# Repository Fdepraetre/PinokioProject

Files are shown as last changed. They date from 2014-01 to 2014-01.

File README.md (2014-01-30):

PinokioProject
==============

pinokio

In the [wiki of this project](https://github.com/Fdepraetre/PinokioProject/wiki) you will find all documentation you need to build the lamp and use it.

[original pinokio site](http://adambendrordesign.wordpress.com/category/mddn-251/)

Python library
--------------
[AX12 python Library](http://pypi.python.org/pypi/dynamixel/1.0.1)

[Python serial library](http://pypi.python.org/pypi/pyserial)

[WXpython](http://wxpython.org/)

[Numpy](http://www.numpy.org/)

[Matplotlib](http://matplotlib.org)

[PyYAML](http://pyyaml.org/)

windows installation
--------------------
if you are under windows you need a 32bit version of python 2.7. You also need to install some extrat library for matplotlib.

* dateutil
* pyparsing
* six
* pytz

[link to download python library for windows](http://www.lfd.uci.edu/~gohlke/pythonlibs/)

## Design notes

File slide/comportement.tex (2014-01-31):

\section{Comportement}
\begin{frame}
  \begin{columns}[c]
    \begin{column}{.5\textwidth}
      \begin{itemize}
        \item Implémentation d'une machine d'état
        \item Trois états :
          \begin{itemize}
            \item Endormi
            \item Recherche de visage
            \item Suivi de visage
          \end{itemize}
      \end{itemize}
    \end{column}
    \begin{column}{.5\textwidth}
      \begin{figure}
        \input{image/stateMachine.tex}
      \end{figure}
    \end{column}
 \end{columns}
\end{frame}

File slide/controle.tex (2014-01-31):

\section{Contrôle des moteurs}
\subsection{Présentation des moteurs}
\begin{frame}
  \frametitle{Présentation des moteurs}
  \begin{columns}[c]
    \begin{column}{.65\textwidth}
           \begin{itemize}
            \item Moteurs utilisés 
            \begin{itemize}
              \item AX-12~ ( 12 kg.cm\up{-1})
              \item MX-28 ( 28 kg.cm\up{-1})
            \end{itemize}
            \item Avantages:
            \begin{itemize}
              \item Bus TTL , une sortie pour tous les moteurs
              \item Communication par bus UART
              \item Gestion de moteur indépendamment ou globalement
            \end{itemize}
          \item Inconvénient:
            \begin{itemize}
              \item Les AX-12 n'ont pas assez de couple
              \item Contrôle PID intégré et réglé sans charge
              \item Moteur pas à pas
            \end{itemize}
          \end{itemize}
        \end{column}
        \begin{column}{.3\textwidth}
          \begin{figure}[ht]
            \centering
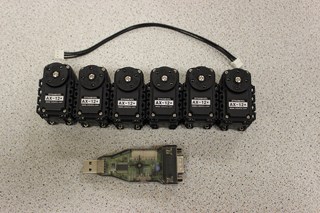
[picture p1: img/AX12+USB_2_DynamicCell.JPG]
            
            \caption{Moteur et interface physique}
          \end{figure}
        \end{column}
      \end{columns}

\end{frame}
\subsection{Configuration et Interface}
\begin{frame}
  \frametitle{Configuration et Interface}
  \begin{columns}[c]
    \begin{column}{.4\textwidth}
      \begin{itemize}
        \item Configuration
          \begin{itemize}
            \item Utilisation de yaml
            \item Port, baudrate, angle limite
          \end{itemize}
        \item Interfaces Utilisateurs
          \begin{itemize}
            \item En ligne de commande
            \item Graphique
          \end{itemize}
      \end{itemize}
    \end{column}
    \begin{column}{.6\textwidth}
      \begin{figure}[ht]
        \centering
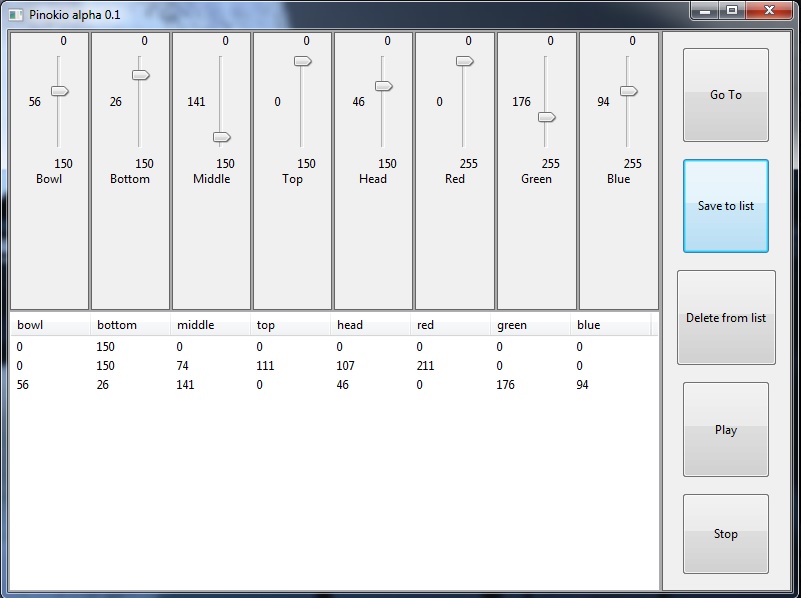
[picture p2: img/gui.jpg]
        
      \end{figure}
    \end{column}
  \end{columns}
\end{frame}
\subsection{Génération de trajectoire}
\begin{frame}
  \frametitle{Génération de trajectoire}
            \begin{figure}
                \begin{center}
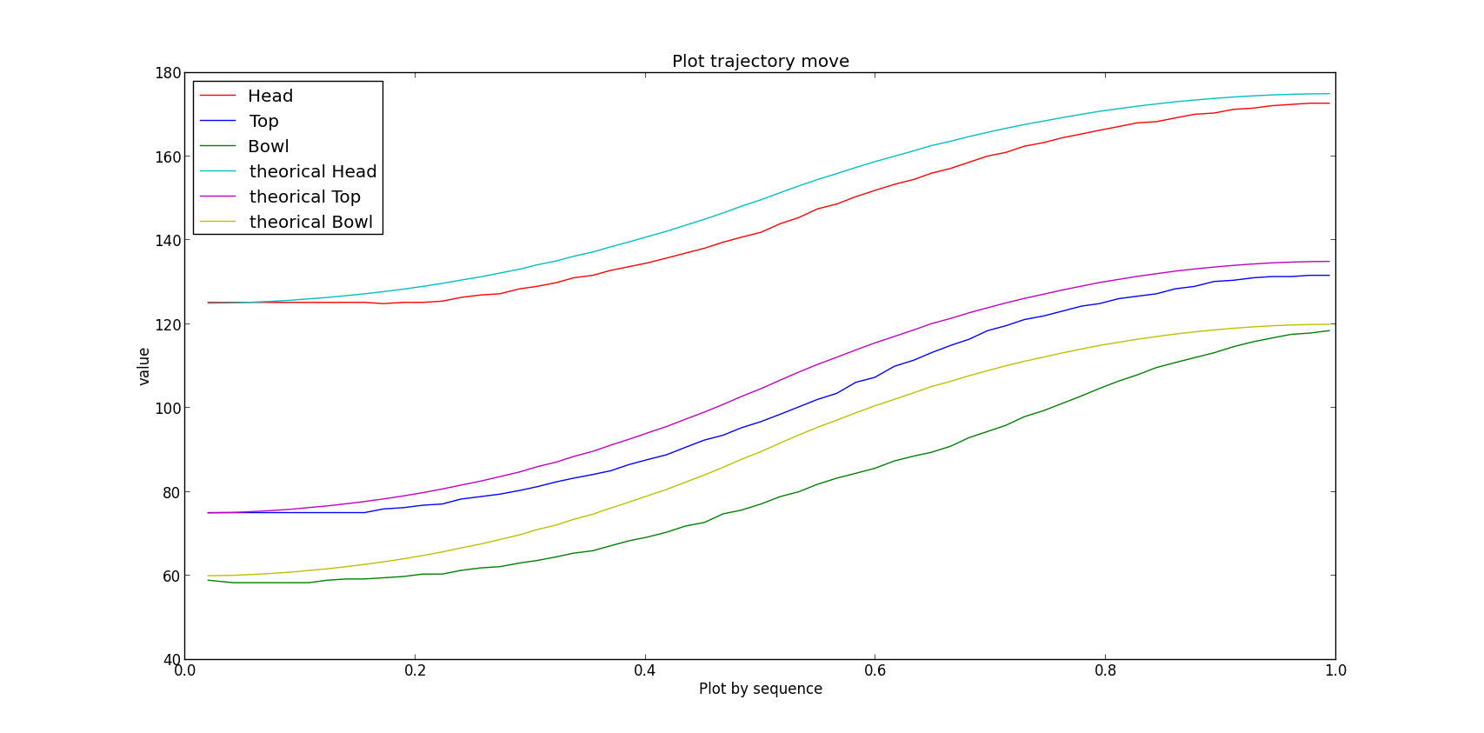
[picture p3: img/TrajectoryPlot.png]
                    
                \end{center}
                \caption{Exemple de génération de trajectoire}
            \end{figure}
\end{frame}

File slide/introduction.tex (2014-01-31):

\section*{Introduction}
\begin{frame}
  \frametitle{Introduction}
  \begin{columns}[c]
    \begin{column}[T]{.5\textwidth}
      \begin{itemize}
        \item Pour l'Inria équipe mnemosyne
        \item Travail demandé
          \begin{itemize}
            \item Reproduire le projet Pinikio
            \item Documenter la réalisation
            \item API simple pour controler le robot
          \end{itemize}
        \item Servira pour l'étude des comportements
      \end{itemize}
    \end{column}
    \begin{column}[T]{.5\textwidth}
      \begin{figure}
        \begin{center}
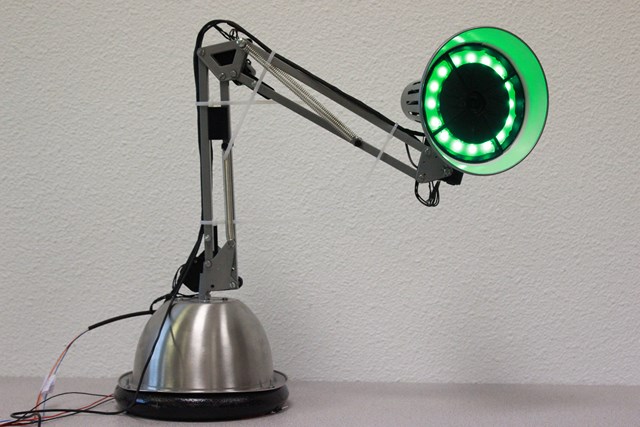
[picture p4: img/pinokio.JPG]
          
        \end{center}
      \end{figure}
    \end{column}
  \end{columns}   
\end{frame}

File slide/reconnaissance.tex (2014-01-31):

\section{Reconnaissance de visage}
\subsection{Détection de visage}
\begin{frame}
  \frametitle{Détection de visage}
  \begin{columns}[c]
    \begin{column}[T]{.5\textwidth}
      \begin{itemize}
        \item Utilisation d'OpenCV
          \begin{itemize}
            \item open source computer vision library
          \end{itemize}
        \item Utilisation de classifieur pour la detection de visage
          \begin{itemize}
            \item Obtention d'un cercle (rayon et centre)
          \end{itemize}
      \end{itemize}
    \end{column}
    \begin{column}[T]{.5\textwidth}
      \begin{figure}
        \begin{center}
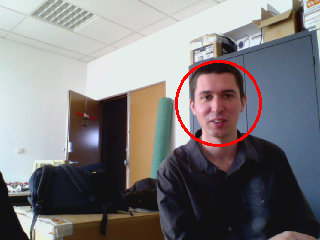
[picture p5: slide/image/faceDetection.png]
          
        \end{center}
      \end{figure}
    \end{column}
  \end{columns}   
\end{frame}

\subsection{Calcul de l'ouverture}
\begin{frame}
  \frametitle{Calcul de l'ouverture}
  \begin{figure}
    \begin{columns}[c]
      \begin{column}[T]{.5\textwidth}
        \input{image/ouverture1.tex}
      \end{column}
      \begin{column}[T]{.5\textwidth}
        \input{image/ouverture2.tex}
      \end{column}
    \end{columns}   
  \end{figure}
\end{frame}

\subsection{Suivi de visages}
\begin{frame}
  \frametitle{Suivi de visages}
  \begin{itemize}
    \item Déterminer :
      \begin{itemize}
        \item la distance au centre de l'image
        \item l'angle horizontal et vertical du visage par rapport au centre 
      \end{itemize}
    \item Déplacer les moteurs de la tête des angles calculés
  \end{itemize}
\end{frame}

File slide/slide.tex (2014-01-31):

\documentclass[handout]{beamer}
 
\usepackage[frenchb]{babel}
\usepackage[T1]{fontenc}
\usepackage[utf8]{inputenc}
\usepackage[footheight=1em]{beamerthemeboxes}
\usepackage{graphics}
\usepackage{graphicx}
\usepackage{tikz}
 
\usetheme{Warsaw}

\title[Projet Pinokio ~~~~~~~~~~~~~~~~~~~~~~~~~~~~~~~~~~~~~~~~~~~~~~ \insertframenumber/\inserttotalframenumber]{Projet Pinokio}
\author[F. Depraetre, T. Lambert, R. Sagean]{Fabien Depraetre, Thibaud Lambert, Romain Sagean}
\institute{ENSEIRB-MATMECA}
\begin{document}

	%% Title Page %%
	\begin{frame}
		\titlepage
	\end{frame}

	%% Plan %%
  \input{introduction.tex}

  \begin{frame}
		\frametitle{Plan}
		\tableofcontents[hideallsubsections]
	\end{frame}

  \input{construction.tex}

  \input{controle.tex}

  \input{reconnaissance.tex}

  \input{comportement.tex}

  \input{conclusion.tex}

\end{document}

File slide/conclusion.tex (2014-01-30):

\section{Conclusion}

\begin{frame}
  \frametitle{Conclusion}
  \begin{itemize}
    \item Beaucoup de temps passé sur la construction
    \item Projet bien documenté
    \item Robot fonctionel et utilisable
    \item Travail à poursuivre
  \end{itemize}
\end{frame}

\begin{frame}
  \begin{center}
    \LARGE Merci de votre attention
  \end{center}
\end{frame}

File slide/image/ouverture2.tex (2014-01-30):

\begin{tikzpicture}[scale=0.5]
 \tikzset{directed/.style={->}} 
  \node[draw, circle, very thick] (CAM) at (0,0) {CAM};
  \node[draw, very thick,color=red] (TARGET) at (6,0) {};
  \node[] (P1) at (3,5.1) {};
  \node[] (P2) at (3,-5.1) {};
  \node[] (P3) at (5.1,3) {};
  \node[] (P4) at (5.1,-3) {};
  \draw[very thick] (CAM) -- (TARGET);
  \draw[very thick] (CAM) -- (P2);
  \draw[dashed] (CAM) -- (P3);
  \draw[dashed] (CAM) -- (P4);
  \draw[directed] (0,0) ++(3,0) node[above right] {$\theta$} arc (0:30:3cm);
  \draw[directed] (0,0) ++(3,0) arc (0:-30:3cm);
%  \fill[very thick] (0.946,0.55) circle (0.2cm);
\end{tikzpicture}

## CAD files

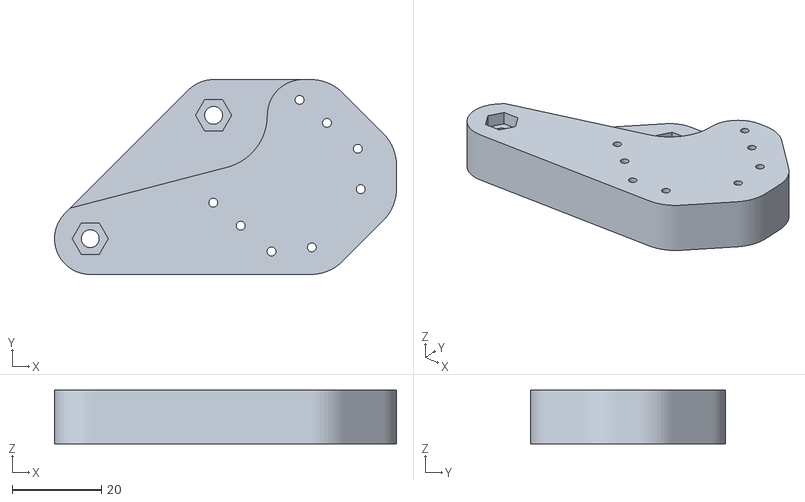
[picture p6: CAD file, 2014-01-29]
parts/bottom_mx28_v1.stl
76.5 x 43.6 x 12.0

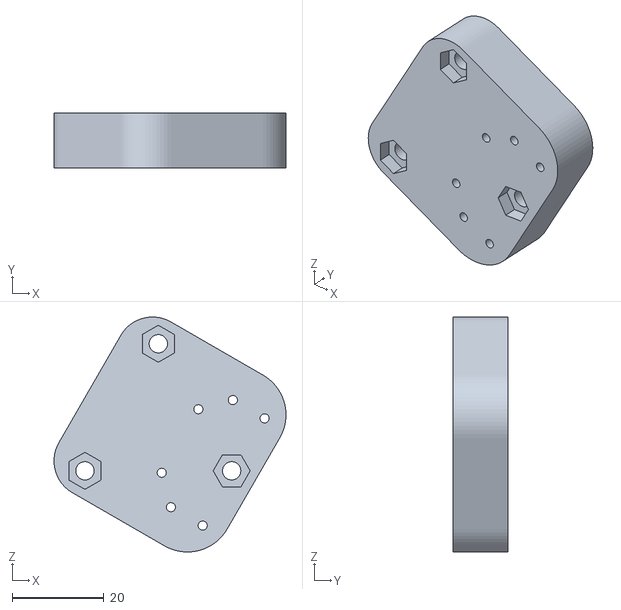
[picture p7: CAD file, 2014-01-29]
parts/oldparts/top_v3.stl
50.6 x 12.0 x 51.3

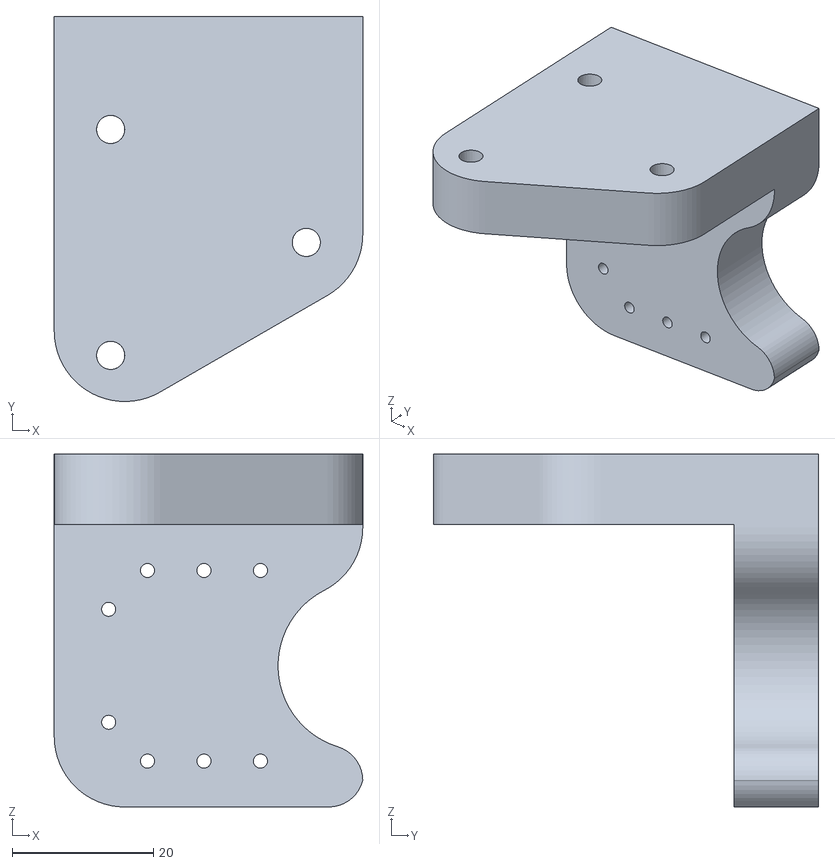
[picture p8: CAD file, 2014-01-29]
parts/top_v4.stl
43.7 x 54.5 x 50.0

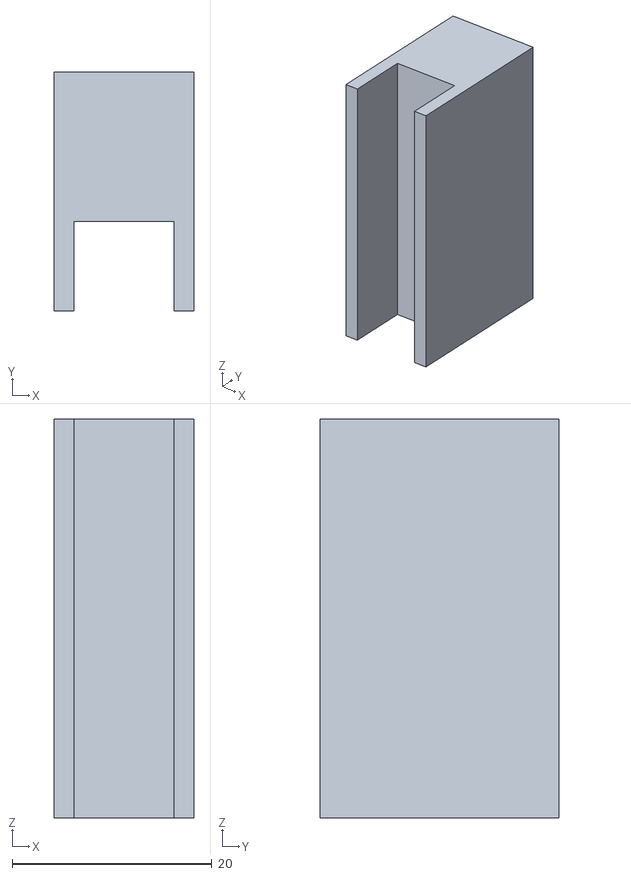
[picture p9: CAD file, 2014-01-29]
parts/bloc.stl
14.0 x 24.0 x 40.0

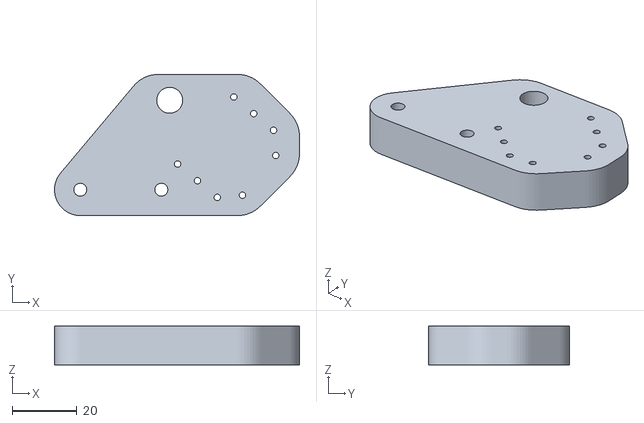
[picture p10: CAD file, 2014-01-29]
parts/oldparts/bottom_ax12_v3.stl
75.6 x 43.6 x 12.0

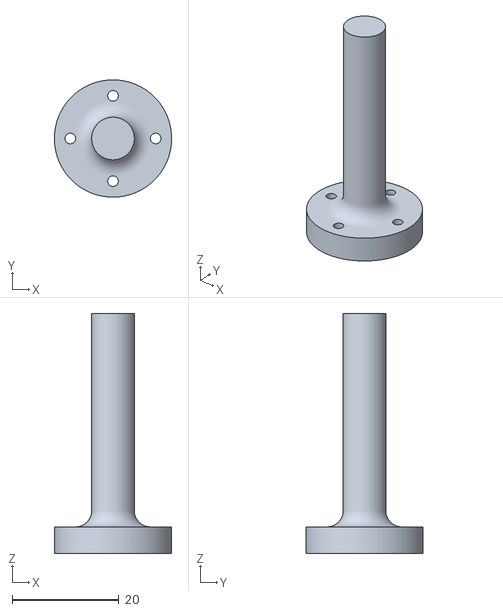
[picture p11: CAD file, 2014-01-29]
parts/ax12tobase.stl
22.0 x 22.0 x 45.0

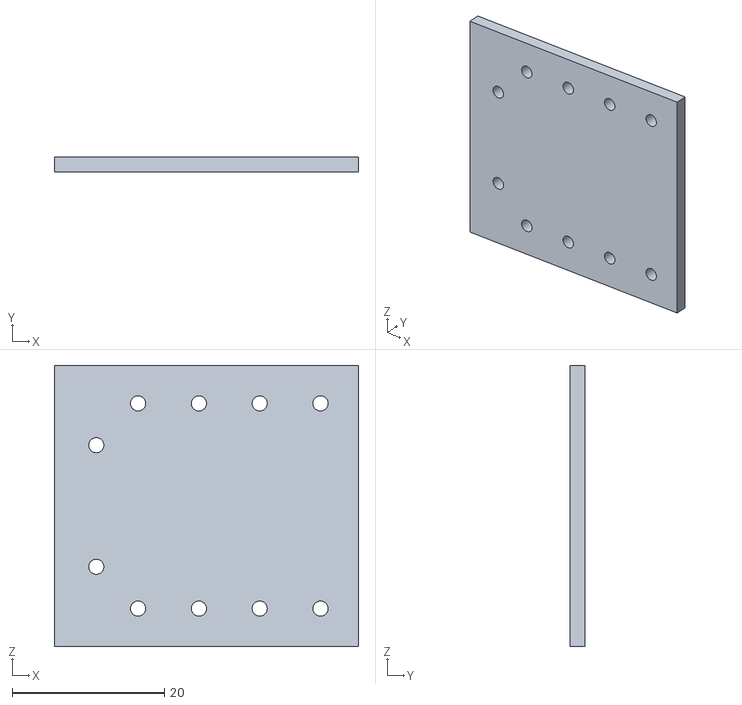
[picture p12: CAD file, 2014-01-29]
parts/oldparts/AX12_gabarit.stl
40.0 x 2.00 x 37.0

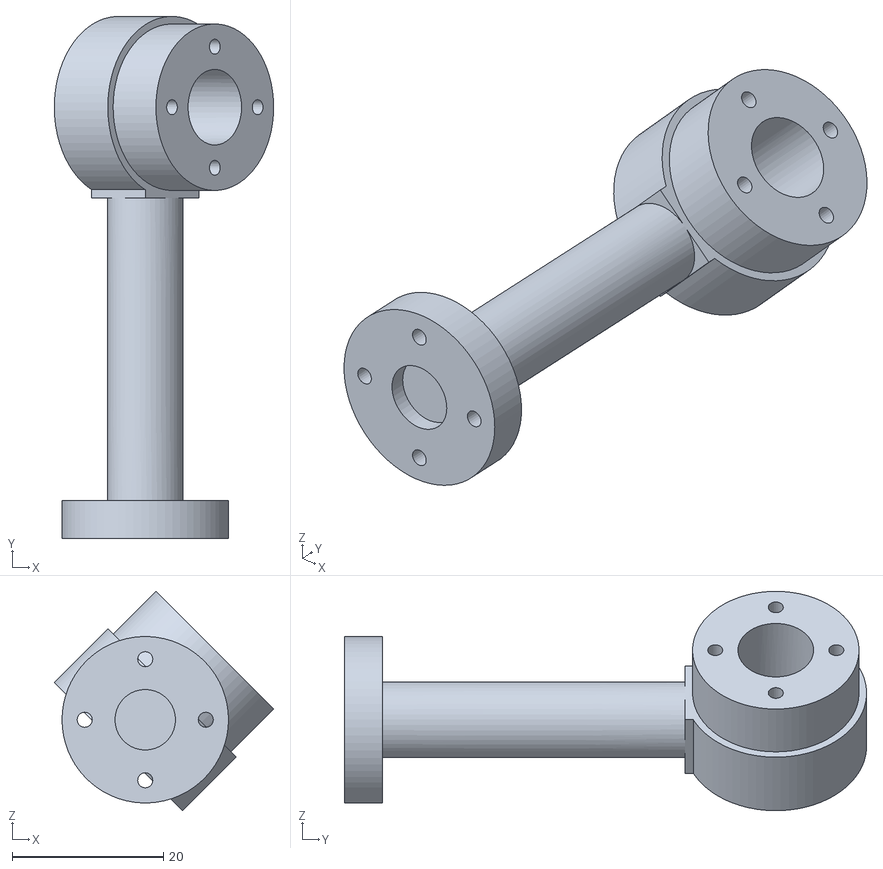
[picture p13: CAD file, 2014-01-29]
parts/neck_v2.1.stl
29.0 x 69.0 x 29.0

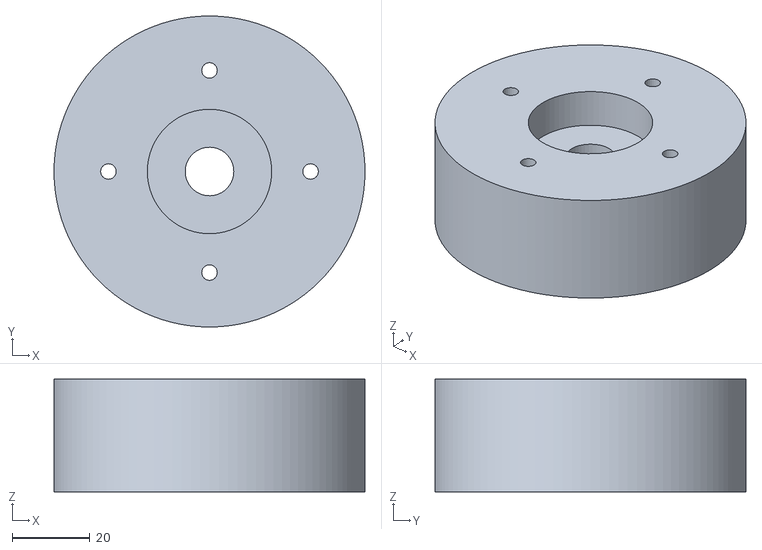
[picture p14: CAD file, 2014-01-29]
parts/bowl_v2.stl
80.0 x 80.0 x 29.0

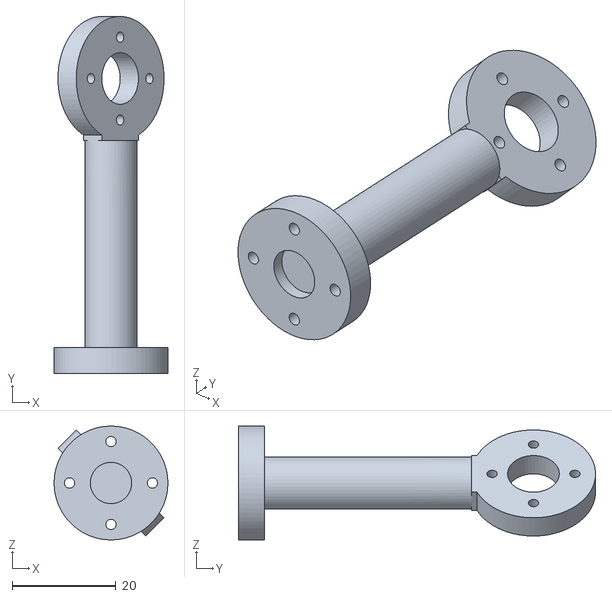
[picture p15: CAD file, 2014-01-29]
parts/oldparts/neck_v2.stl
22.0 x 69.0 x 22.0

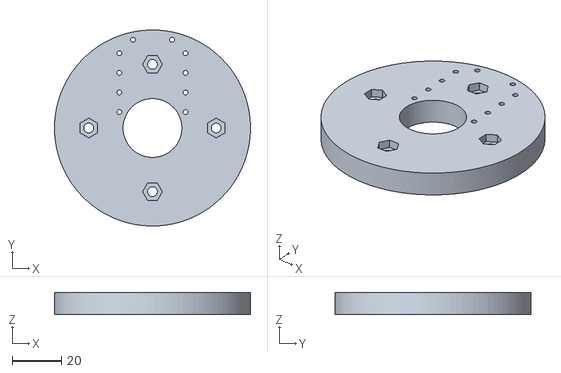
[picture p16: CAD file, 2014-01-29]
parts/bowl_ax12_support_v2.stl
80.0 x 80.0 x 9.00

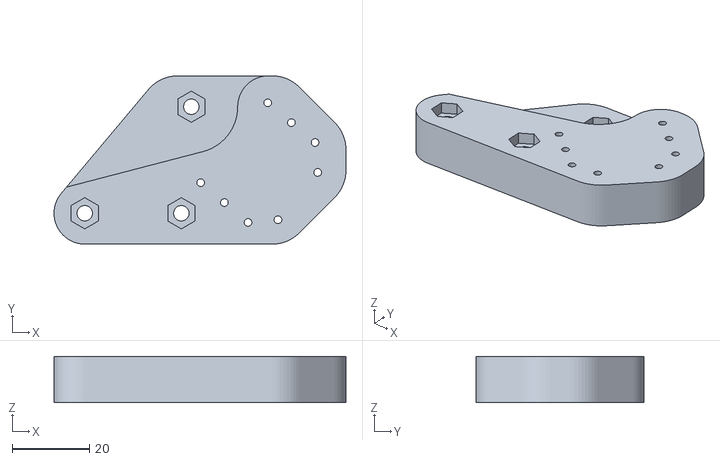
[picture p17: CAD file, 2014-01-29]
parts/oldparts/bottom_right_ax12_v3.stl
75.6 x 43.6 x 12.0

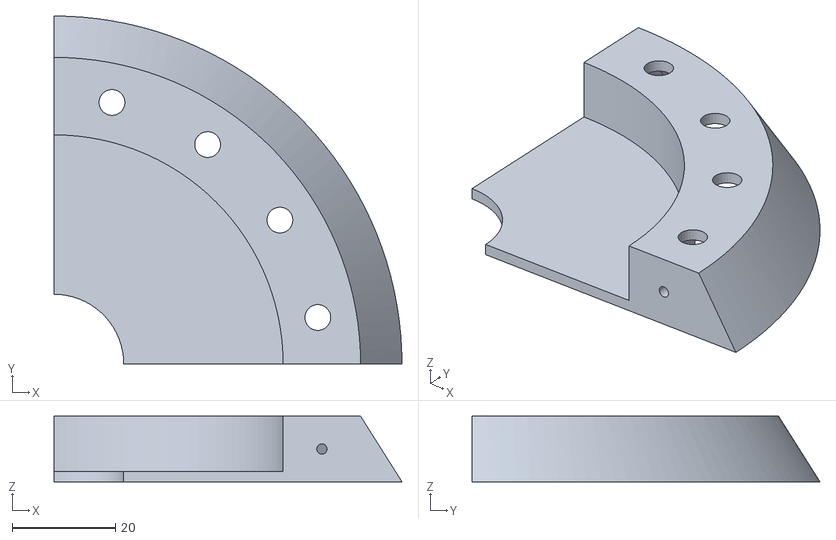
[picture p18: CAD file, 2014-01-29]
parts/Led_circle.stl
67.4 x 67.4 x 12.7

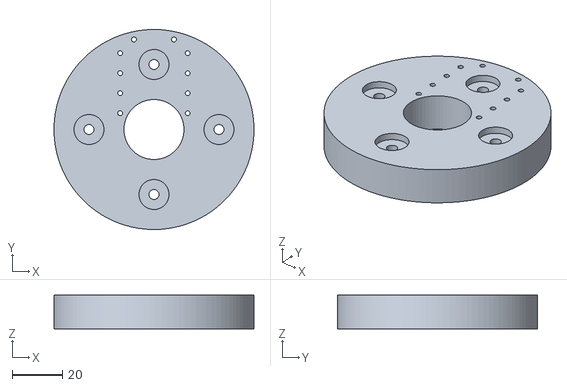
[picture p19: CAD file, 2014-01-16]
parts/oldparts/bowl_ax12_support.stl
80.0 x 80.0 x 13.5

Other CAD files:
parts/head_inside.stl
parts/middle_v1.stl
parts/oldparts/bowl_v1.stl
parts/ax12tobase.ipt
parts/bloc.ipt
parts/bottom_mx28_v1.ipt
parts/bowl_ax12_support_v2.ipt
parts/bowl_v2.ipt
parts/head_inside.ipt
parts/led_circle.ipt
parts/middle_v1.ipt
parts/moving_arm.ipt
parts/moving_arm.stl
parts/neck_v2.1.ipt
parts/oldparts/AX12_gabarit.ipt
parts/oldparts/bottom_ax12_v1.ipt
parts/oldparts/bottom_ax12_v1.stl
parts/oldparts/bottom_ax12_v2.ipt
parts/oldparts/bottom_ax12_v3.ipt
parts/oldparts/bottom_right_ax12_v3.ipt
parts/oldparts/bowl_ax12_support.ipt
parts/oldparts/bowl_v1.ipt
parts/oldparts/neck.ipt
parts/oldparts/neck.stl
parts/oldparts/neck_v2.ipt
parts/oldparts/top_v1.ipt
parts/oldparts/top_v1.stl
parts/oldparts/top_v2.ipt
parts/oldparts/top_v2.stl
parts/oldparts/top_v3.ipt
parts/top_circle.ipt
parts/top_circle.stl
parts/top_v4.ipt

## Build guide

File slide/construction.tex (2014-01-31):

\section{Construction}

\subsection{Fixation des moteurs}
\begin{frame}
  \frametitle{Fixation des moteurs}
  \begin{columns}[c]
    \begin{column}[c]{.5\textwidth}
      \begin{itemize}
        \item moteur vissé sur la pièce en plastique
        \item pièces en plastique vissées sur les articulations
        \item empreinte pour les écrous
        \item facile à assembler et désassembler
      \end{itemize}
    \end{column}
    \begin{column}[c]{.5\textwidth}  
      \begin{figure}
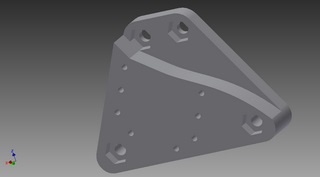
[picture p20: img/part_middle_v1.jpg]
        			
      \end{figure}
    \end{column}
  \end{columns}
\end{frame}

\subsection{Problèmes rencontrés}
\begin{frame}
  \frametitle{Problèmes rencontrés}
  \begin{columns}[c]
    \begin{column}[c]{0.5\textwidth}
	  \begin{itemize}
	    \item pièce bottom 
	      \begin{itemize}
	        \item 1*AX12
	        \item 2*AX12 
	        \item 1*MX28
	        \item raccourcissement des tubes
	      \end{itemize}
	    \item pièce top
	      \begin{itemize}
	        \item buté contre le plastique
	        \item inversement des axes de rotation des moteurs
	      \end{itemize}
	    \item pièce neck
	      \begin{itemize}
	        \item casse de la pièce
	      \end{itemize}
	  \end{itemize}
    \end{column}
    \begin{column}[c]{0.5\textwidth}
      \begin{figure}
      	\begin{center}
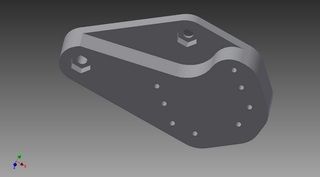
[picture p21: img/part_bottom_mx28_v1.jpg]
      		
      	\end{center}      
      \end{figure}
    \end{column}
  \end{columns}
\end{frame}

\subsection{Contrôle des LED}
\begin{frame}
  \frametitle{Contrôle des LED}
  \begin{columns}[c]
    \begin{column}[T]{0.5\textwidth}
      \begin{itemize}
        \item arduino
        \item utilisation de transistors
        \item communication série pour changer de couleur
      \end{itemize}
    \end{column}
    \begin{column}[T]{0.5\textwidth}
      \begin{figure}
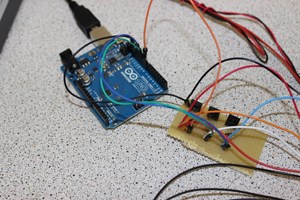
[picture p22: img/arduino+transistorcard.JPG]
        
      \end{figure}
    \end{column}
  \end{columns}
\end{frame}

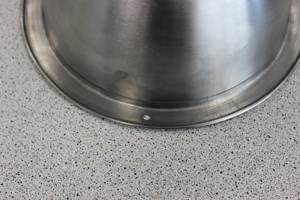
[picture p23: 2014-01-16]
img/bowl_step2.JPG

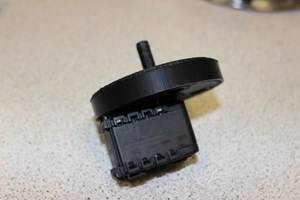
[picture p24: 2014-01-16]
img/base_step6.JPG

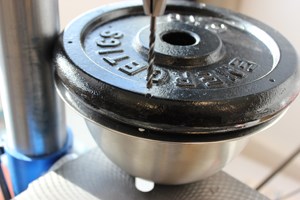
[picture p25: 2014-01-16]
img/bowl_step1.JPG

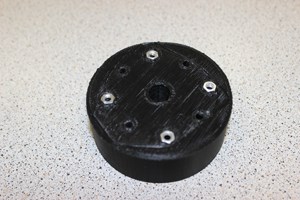
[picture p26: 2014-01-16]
img/base_step1.JPG

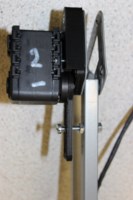
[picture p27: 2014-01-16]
img/joint2_step7.JPG

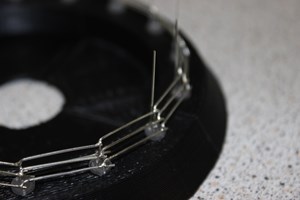
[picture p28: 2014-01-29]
img/led_step_5.JPG

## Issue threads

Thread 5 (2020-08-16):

arduino

marianne1901, 2020-08-16:
I know it has been a long time since you've been here but your project is so awesome that I hope you can answer my question...
I downloaded everything, build the entire lamp but I do not know where to start with the software...
Where can I find the initial / starting sketch for Arduino?

Hope to hear from you!

scauglog, 2020-08-16:
Indeed this was a long time ago. The arduino is only used to control the led. You should upload the .ino file in src/arduino/RGB_led_serial_control to your arduino. To control the actuator (dynamixel) you need a USB to dynamixel adaptator. to control the lamp you have
- a python GUI in `python src/prog/guiClient.py`
- the demo (sleep, search face and follow) `python src/prog/behaviorClient.py`
You need to have a python 2.7 client on your machine with library listed in the Readme.

marianne1901, 2020-08-17:
I am really thankful!
I ordered dynamixel actuators but it's taking too long so I already build it with cheap MG995 servo's.
Hoping they could do the job also if I altered the .ino file.
I think I have to be patient and wait a little longer for the dynamixel actuators.
Thanks again, and when the arrive I will give you s short notice how everything went!

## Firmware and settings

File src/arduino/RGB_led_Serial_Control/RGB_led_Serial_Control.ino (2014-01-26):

int red=9;
int green=10;
int blue=11;

int length=4; //buffer length
byte byteCount;
char endCmd='\n';

long time=0;
int periode = 10000;
int value;
boolean fading=false;
char color;

void setup(){
  pinMode(red,OUTPUT);
  pinMode(green,OUTPUT);
  pinMode(blue,OUTPUT);
  Serial.begin(9600);
  Serial.setTimeout(10);
   analogWrite(red,0);
   analogWrite(green,0);
   analogWrite(blue,0);
}

void loop(){
 char buffer[length];
 byteCount=-1;
 byteCount=Serial.readBytesUntil(endCmd, buffer, length); //read length char or until endCmd
 if(byteCount==4 && buffer[0]=='l'){
   analogWrite(red,buffer[1]);
   analogWrite(green,buffer[2]);
   analogWrite(blue,buffer[3]);
   fading=false;
 }
 if(byteCount==3 && buffer[0]=='f')
 {
   fading=true;
   color=buffer[1];
   periode=buffer[2]*100;
   analogWrite(red,0);
   analogWrite(green,0);
   analogWrite(blue,0);
 }
 if(fading){
   time = millis();
   value = 128+127*cos(2*PI/periode*time);   
   if(color=='r'){
     analogWrite(red,value);
   }else if (color=='g'){
     analogWrite(green,value);
   }else if (color=='b'){
     analogWrite(blue,value);
   }
 }
 
}

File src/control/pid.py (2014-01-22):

import time


class PIDcontroler:

  def __init__(self,proportionalCoeff,integralCoeff,derivateCoeff,maxIntegral=0,maxDerivate=0,length=1):

    self.proportionalCoeff = proportionalCoeff
    self.integralCoeff     = integralCoeff
    self.derivateCoeff     = derivateCoeff
    self.maxIntegral       = maxIntegral
    self.maxDerivate       = maxDerivate
    self.lastIn            = []
    self.integralValue     = []
    self.timeInit = time.time()

    for i in range(length):
      self.lastIn            += [0]
      self.integralValue     += [0]

  def update(self,reference,returnValue):

    derivate = []
    error    = []
    command  = []
    
    timeElapsed = time.time() - self.timeInit

    for i in range(len(reference)):
      derivate += [0]
      error    += [0]
      command  += [0]

      error[i] += reference[i] - returnValue[i]
      self.integralValue[i] += error[i] * timeElapsed
      if self.maxIntegral !=0:
        max(self.integralValue[i],self.maxIntegral)

      derivate[i] = error[i] - self.lastIn[i] / timeElapsed
      if self.maxDerivate != 0:
        max(derivate[i],self.maxDerivate)

      command[i] = error[i] * self.proportionalCoeff + self.integralValue[i] * self.integralCoeff + derivate[i] * self.derivateCoeff

      print "error " + str(error)
      print "intValue " +str(self.integralValue)

    self.lastIn = error

    return command


  time.sleep(2)
if (__name__)=='__main__':


  pid = PIDcontroler(2,0,0,maxIntegral= 500,length=1)
  positionMesured = [[10],[40],[70],[140],[149],[149],[149],[149],[149]]

  outPid = []
#  time.sleep(0.5)
  outPid = pid.update([150],[2])
  print outPid



  for i in range(len(positionMesured)):
      
      outPid = pid.update([150],positionMesured[i])
      time.sleep(0.5)
      print "outPid" + str(outPid) + "\n"

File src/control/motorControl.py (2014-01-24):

import sys
import dynamixel
import time
import random
import sys
import optparse
import plot
sys.path.insert(0, "../settings/")
import settings
import math

class Motor:

  def __init__(self,motor,name,minAngle = 0,maxAngle = 300 ):
    self.motor    = motor
    self.maxAngle = maxAngle
    self.minAngle = minAngle
    self.valeur   = 0
    self.name     = name

  def setAngle(self,angle):
    """ Set the motor angle """
    if angle > self.maxAngle or angle < self.minAngle:
      print "Angle out of range"
      print "motor : " + str(self.name)
      print "value : " + str(angle)
      print "range : [" + str(self.maxAngle) + "," + str(self.minAngle) + "]"
    else:
      if self.name == "bottom":
        fact = 6.82
      else:
        fact = 3.41
      self.motor.goal_position = int(fact * angle)

  def setSpeed(self,speed):
       self.motor.moving_speed = speed

  def setSynchronize(self,synchronized):
       self.motor.synchronized = synchronized

  def readMotorPosition(self):
      if self.name == "bottom":
        fact = 6.82
      else:
        fact = 3.41
      self.motor.read_all()
      return self.motor.current_position / fact
  
  def getRange(self):
    return [self.minAngle,self.maxAngle]


class MotorControl:
   
  def __init__(self,settings):
    self.portName       = settings['port']
    self.baudRate       = settings['baudRate']
    self.motorConfig    = settings['motorConfig']
    self.motors         = [] 
     
    # Establish a serial connection to the dynamixel network.
    # This usually requires a USB2Dynamixel
    serial   = dynamixel.SerialStream(port        = self.portName, baudrate = self.baudRate, timeout = 1)
    self.net = dynamixel.DynamixelNetwork(serial)
    self.idList = []
    self.nameList = []

    print "Scanning for Dynamixels..."
    for conf in self.motorConfig:
      self.idList += [conf[0]]
      self.nameList += [conf[3]]
    self.net.scan(min(self.idList),max(self.idList))
    for conf in self.motorConfig:
      if conf[0] in [motor.id for motor in self.net.get_dynamixels()]:
        print "motor " + str(conf[3]) + " has been found"
        self.motors += [Motor(self.net[conf[0]],conf[3],conf[1],conf[2])]
      else:
        print "motor " + str(conf[3]) + " has not been found"
        self.motors += [None]
    self.setAllSpeed()
        
     
  def setAllSpeed(self,speed=100):
    """ Set the speed for every motors """
    # Ping the range of servos that are attached
    for motor in self.motors:
      if motor != None :
        motor.setSpeed(speed)

  def setSynchronize(self,synchronized = True):
    """ Set the synchronization for every motors """
    for motor in self.motors:
      if motor != None :
        motor.setSynchronize(synchronized)

  def setMotorsById(self,values):
    """ Set the angle motor by ID ( values is a list of tuple [ motorId , Angle]) """
    for val in values:
      if val[0] in self.idList :
        index = self.idList.index(val[0])
        if self.motors[index] != None:
          self.motors[index].setAngle(val[1]) 
    self.net.synchronize()
    #time.sleep(0.1)

  def setMotorsByName(self,values):
    """ Set the angle motor by name ( values is a list of tuple [ motorName , Angle]) """
    for val in values:
        if val[0] in self.nameList :
            index = self.nameList.index(val[0])
            if self.motors[index] != None:
                self.motors[index].setAngle(val[1]) 
    self.net.synchronize()
    #time.sleep(0.1)

  def readAllMotors(self):
    """Return each motor position in tick motor  """
    out = []
    for motor in self.motors:
      if motor != None:
        motor.motor.read_all()
        out += [motor.readMotorPosition()]
      else:
        print "motor not connected"
    return out

  def readMotorByName(self,values):
    """Return each motor position in values in tick motor  """
    out = []
    for val in values:
     index = self.nameList.index(val)
     if self.motors[index]!= None:
       self.motors[index].motor.read_all()
       out += [self.motors[index].readMotorPosition()]
     else:
       print "Motor not connected"
    return out

  def getRangeByName(self,names):
    """ Return the motor range for motor in names """
    out = {}
    for name in names:
      index = self.nameList.index(name)
      if self.motors[index]!= None:
        out[name] = self.motors[index].getRange()
      else:
        print "Motor not connected"
    return out

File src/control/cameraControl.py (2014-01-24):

import sys
sys.path.insert(0,"../computerVision/")
import FaceDetection
import VideoStream
import math

ApertureAngle = [50.,30.]

class CameraControl:
    
  def __init__(self, motorControler, faceStream, precision, res, apertureAngle):
    self.p = 1 #0.25

    assert len(res) == 2, 'res have to be of size 2'
    assert len(apertureAngle) == 2, 'apertureAngle have to be of size 2'

    self.precision = [precision * res[0], precision * res[1]]
    self.res = res
    self.apertureAngle = apertureAngle

    self.motorControler = motorControler
    self.faceStream = faceStream

  def positionCamera(self, position):
    """ Determine the changing on camera angle """
    # Initialisation
    angleAddition = []
    
    print "___"
    for i in range(len(position)):
      if self.precision[i] < abs(position[i] - self.res[i]/2) :
        angleAddition += [-(self.apertureAngle[i] / self.res[i]) * (position[i] - self.res[i]/2) * self.p]
      else:
        angleAddition += [0]
      if(i==1):
        print ""
        print "Position :" + str(position[i] - self.res[i]/2)
        print "Angle :" + str(angleAddition[i])
    print "___"
    return angleAddition


  def readHead(self):
    """ Return the angle of the head """
    angle = self.motorControler.readMotorByName(["top","head"])
    return angle
 
  def moveHead(self,angle):
    """ Move head at angle """ 
    self.motorControler.setMotorsByName([["top",angle[0]],["head",angle[1]]])

  def updateControl(self):
    """ Update the head control """
    angle = self.readHead()
    if len(self.faceStream.faceDetection.faces) > 0:
      modAngle = self.positionCamera(self.faceStream.getFacePosition())
      self.moveHead([angle[0]+modAngle[0],angle[1]+modAngle[1]])
    

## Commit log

2014-01-14 add plans file for parts
    [joint2+ax12print.ipt, joint2+ax12print.stl, joint3+ax12imprint.ipt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]
2014-01-15 Motor control
2014-01-16 add missing parts
    [ax12tobase.ipt, ax12tobase.stl, bowl.ipt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]
2014-01-17 Adding function with actuators name
2014-01-17 Plotting actuator tick curves
2014-01-17 Update Angle out of range + delete print
2014-01-20 Adding control on camera
2014-01-20 Rename directory and file (arm->motorControl)
2014-01-20 Modification on camera controler
2014-01-20 rename camera
2014-01-20 Rename and correction import
    [cameraControl.py, motorControl.py, plot.py]
2014-01-20 Smoothing camera mooving
2014-01-20 Smoothing Camera v2
2014-01-20 Update cameraControl
2014-01-21 Fixing problem on motor Control
    [motorControl.py]
2014-01-21 Adding PID Controller on list
2014-01-21 Correction + follow face
    [cameraControl.py, motorControl.py]
2014-01-21 Refactoring + Rename jointMatrix -> trHomogene
2014-01-22 Update MGD + settings for model
    [motorSettings.yaml]
2014-01-22 Adding electronic card to branch on arduino
    [led.brd, led.sch]
2014-01-22 Correction precision cameraControl
2014-01-22 led color control with arduino and python code
2014-01-22 Modification on computing PID
2014-01-22 Cleaning status + Arduino led control
2014-01-22 Adding Led control with face detection
2014-01-22 Config motor range + Add new command for cli
    [motorSettings.yaml]
2014-01-23 Some modification on traj & test arduino
2014-01-23 Adding commentary on motorControl
2014-01-23 Adding commentary on Arduino
2014-01-23 Minor correction
    [motorSettings.yaml]
2014-01-24 add led control to gui create a settings class to set arduino port and baudrate
2014-01-24 Update settings motor
    [motorSettings.yaml]
2014-01-24 Correction test with new motor settings
2014-01-26 GUI that correctly fit the windows under linux
    [gui.py]
2014-01-26 add fadding method on arduino and reduce serial waiting to 10ms. usage : send via serial f + first char of color + period/100. also change usage of color setting now send 'l'+red value+green value+bl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
    [RGB_led_Serial_Control.ino, python2arduino.py]
2014-01-29 add led photo
2014-01-29 add common anode led img
2014-01-29 Adding led board image
2014-01-29 modification on board positioning
    [led.brd, led.sch]
2014-01-29 adding ledController
2014-01-29 add older parts in a folder
    [AX12_gabarit.ipt, AX12_gabarit.stl, Led_circle.stl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]
2014-01-30 Start arduino before init actuator
2015-03-08 Ajout d'un fichier de config pour le joystick
2015-03-08 Rajout du test pour la recopie de valeur à partir d'un joystick
